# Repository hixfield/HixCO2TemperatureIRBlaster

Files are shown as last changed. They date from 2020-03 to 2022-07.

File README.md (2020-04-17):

![Build with PlatformIO](https://img.shields.io/badge/build%20with-PlatformIO-orange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)




Hardware (schematic and PCB) and software for a WIFI connected device offering lots of functionality: CO2 measuring, IR Transmitter, IR receiver and temperature sensor.
As output it has an OLED display, and RGB LED and beeper. Its based on the ESP8266 microcontroller and tts part of my home automation system based on a raspberry pi running Mosquitoo, Nodered, InfluxDB and Grafana.

## Improvements
- [ ] Add temperature offset in firware (seams device is reading hotter then ambient?)
- [ ] Switch to a passive buzzer (should get rid of the reset beeping)
- [ ] Add PCB jumper (solder) to endable/disable buzzer
- [ ] Configuration of WIFI SSID/PWD via web interface
- [ ] Extend firmware to support learning IR codes
- [ ] Extend firmware for remote sending on AC commands

## Brief overview

- Schematic and PCB design in Eagle
- WIFI connected
- MQTT firmware written using PlatformIO
- Plugs in the mains (no need for any USB seperate power brick)
- IR output: PCB has 3 possible positions for the IR Led just use the one convenient for you
- IR input (can be usefull to learn IR codes)
- measures the room temperature via DS18B20
- RGB Led to show green-orange-red depending on CO2 concentration
- Beeper on board
- 32x128 OLED dispaly
- based on popular [ESP8266](http://esp8266.com)

## Youtube movies

| 3D case design in Fusion 360. | Putting case and PCB together |
|---|---|
|3D case design in Fusion 360 (https://www.youtube.com/watch?v=IMcJwMR-dLY)|Putting case and PCB together (https://www.youtube.com/watch?v= ViuAWiBjCa4)

# overview
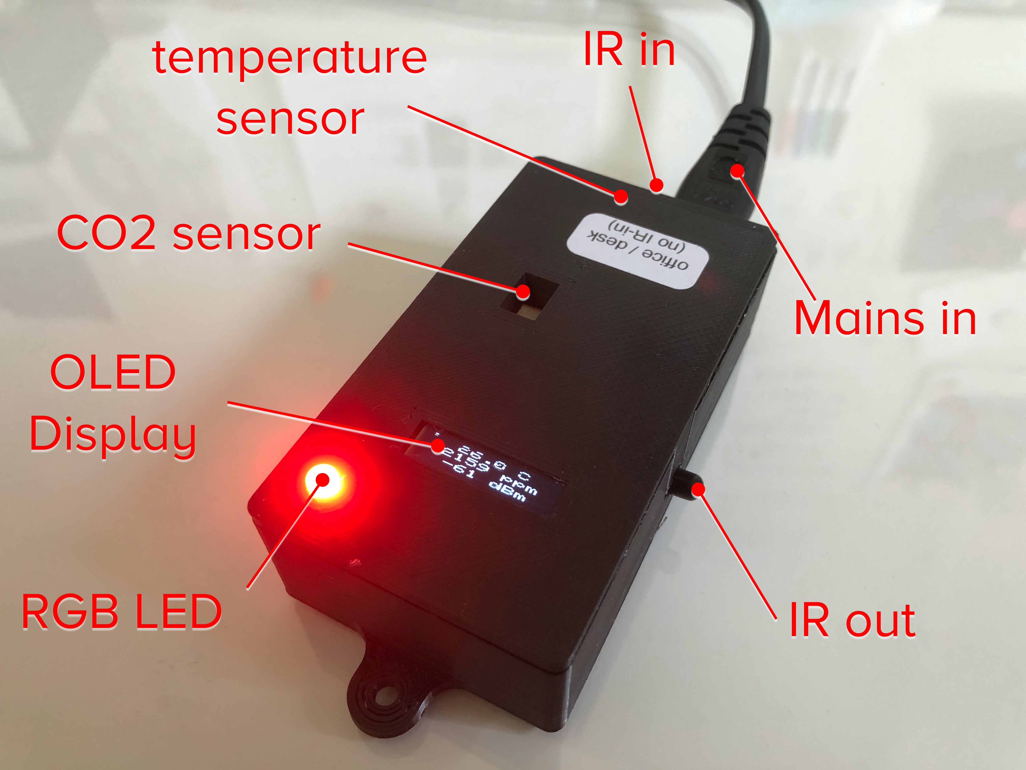
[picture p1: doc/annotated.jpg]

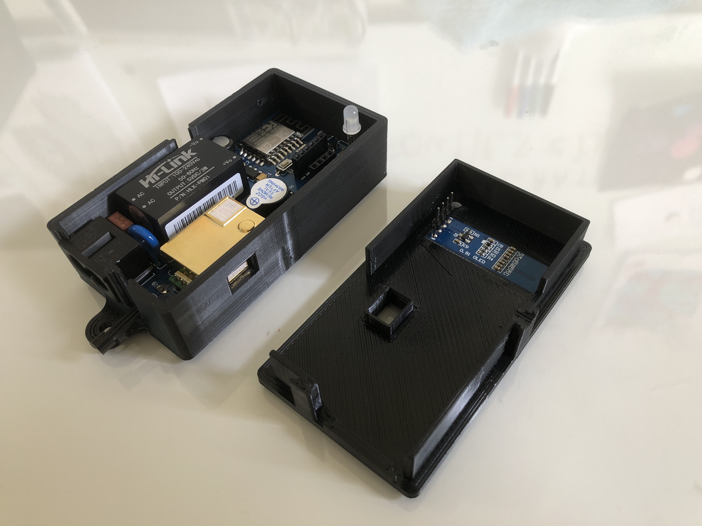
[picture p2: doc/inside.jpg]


# Hardware

[Click here for hardware information](hardware/README.md)

# Software

[Click here for software information](software/README.md)

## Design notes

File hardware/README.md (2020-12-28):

# HixCO2TemperatureIRBlaster - Hardware
The respository contains the EagleCAD file + JLCPCB zip export (in the `/hardware` folder)

| Top | Bottom |
|---|---|
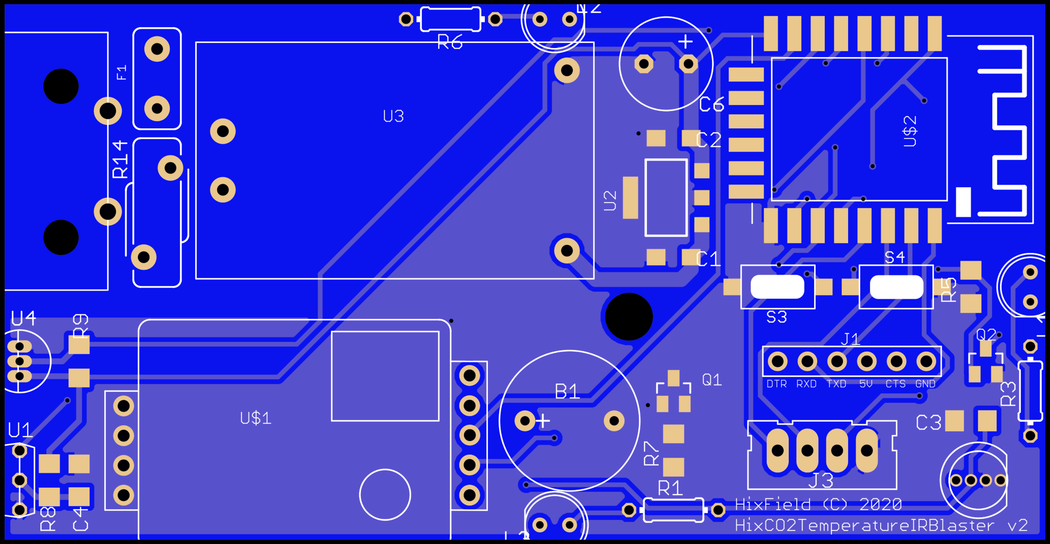
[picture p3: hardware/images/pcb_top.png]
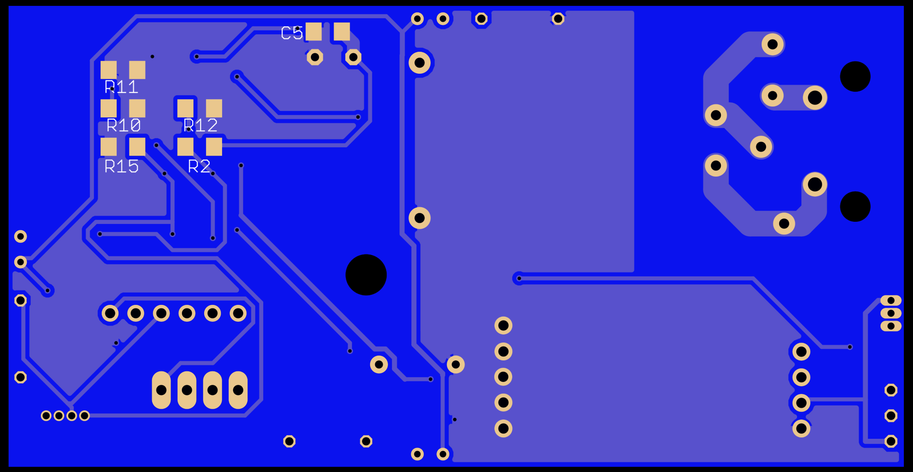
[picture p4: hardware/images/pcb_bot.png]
|  |  |

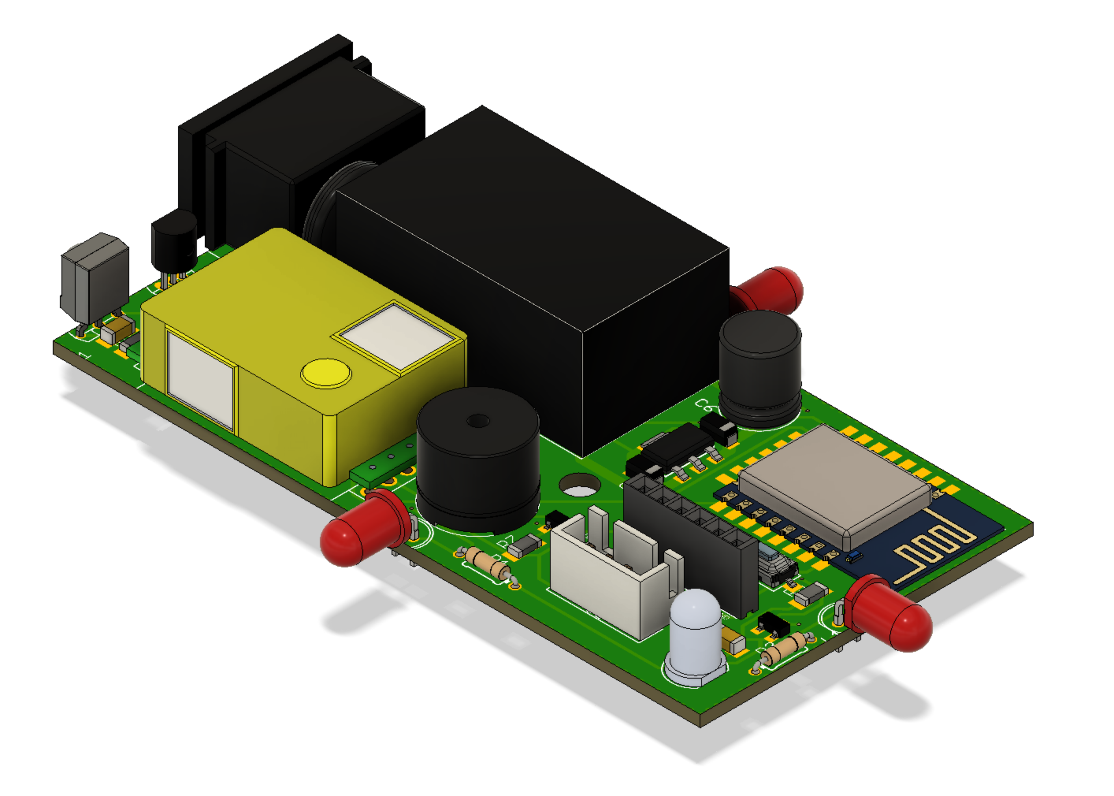
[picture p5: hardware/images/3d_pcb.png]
3D PCB


# BOM
## Base
| ID | Part |
|---|---
|B1 | BUZZER(12MM) 
|C1, C2 | 47uF (SMD 1206) 
|C3, C5 | 100nF (SMD 1206) 
|C6 | 680uF/6.3V 
|F1 | Fuse 800mA 250V 
|J1 | Header female 6 pin
|J2 | IEC320C8 mains connector 
|J3 | Header female 4 pin or XH4P 
|Q1 | Mosfet AO3400 
|R2, R7, R10, R11, R15 | 10K (SMD 1206) 
|R9 | 4.7K (SMD 1206)
|R12 | 2.2K (SMD 1206)  
|R14 | S10K275 
|S3, S4 | SMD Push button 
|U$2 | ESP8266(ESP12E)V2
|U$3 | RGB LED 5mm 
|U1 | TSOP2238 
|U2 | LM3940 (SMD) 
|U3 | HLK-PM01 (mains to 5v powerbrick) 
|U4 | DS18B20 *Eventhough I have designed the PCB to allow mounting a plain TO-92 DS18B20 externally, it seams to be highly inaccurate because (I suspect) it takes over the heat via its leads from the internal of the case/pcb. Therefore it is better to use an external DS18B20 probe. I have included a case design for a plain TO-92 and external sensor probe (with strain relief).*

## IR blasting (optional)
| ID | Part |
|---|---
|L1, L2, L3 | IR LED 100 mA. -> only assemble the one that points in the direction right for you!
|Q2 | Mosfet AO3400 
|R1, R3, R6 | 68 Ohm (SMD 1206) -> only assemble for the LED that points in the direction right for you! 
|R5 | 10K (SMD 1206) 

## IR receiving (optional)
| ID | Part |
|---|---
|C4 | 4.7uF (SMD 1206) 
|R8 | 100 Ohm (SMD 1206) 
|U1 | TSOP2238 

# Schematic
The repository contains the EagleCAD (in the `/hardware` folder)

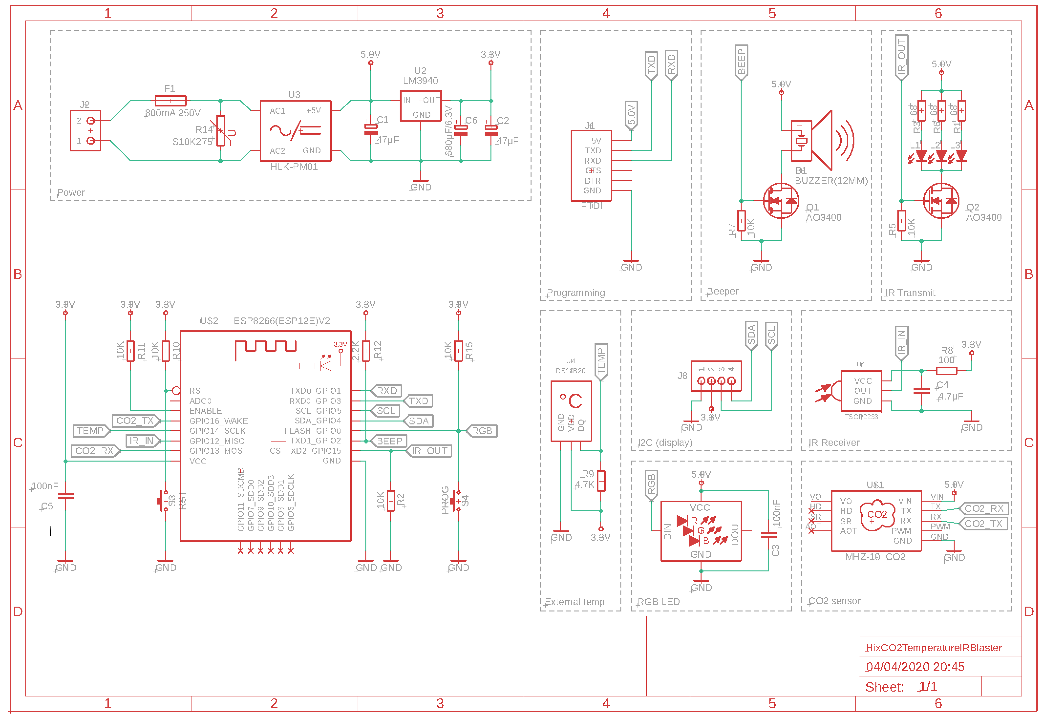
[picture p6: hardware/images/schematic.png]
Schematic


# 3D printed case
(the repository contains the stl files (`/hardware/case` folder)

## external DS18B20 sensor probe
| base | lid |
|---|---|
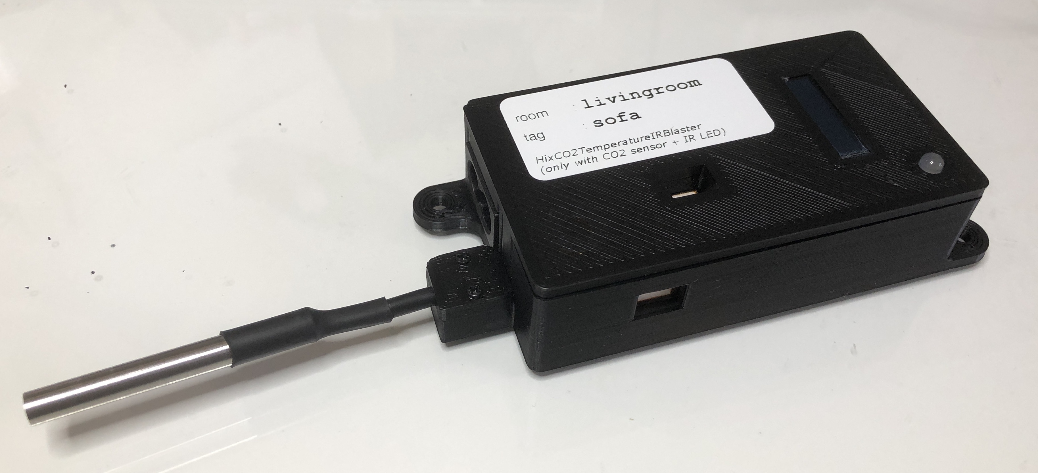
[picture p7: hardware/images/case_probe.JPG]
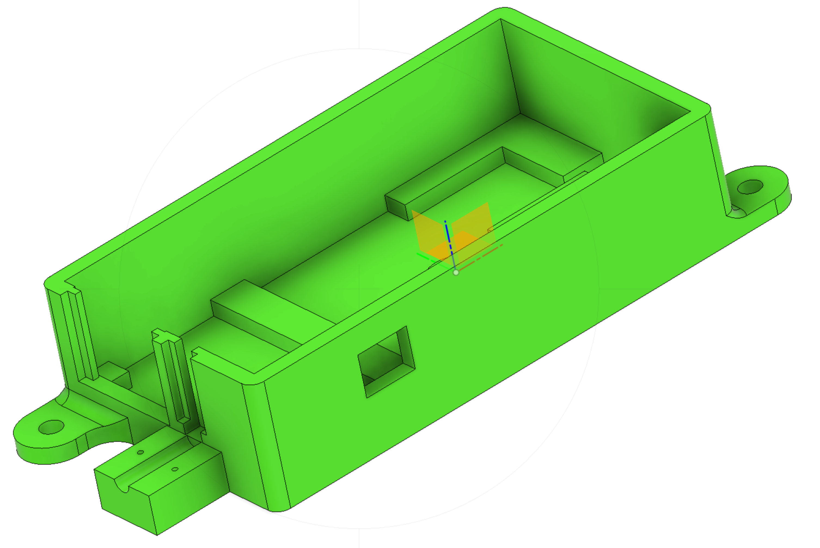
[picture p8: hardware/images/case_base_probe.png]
|  |  |
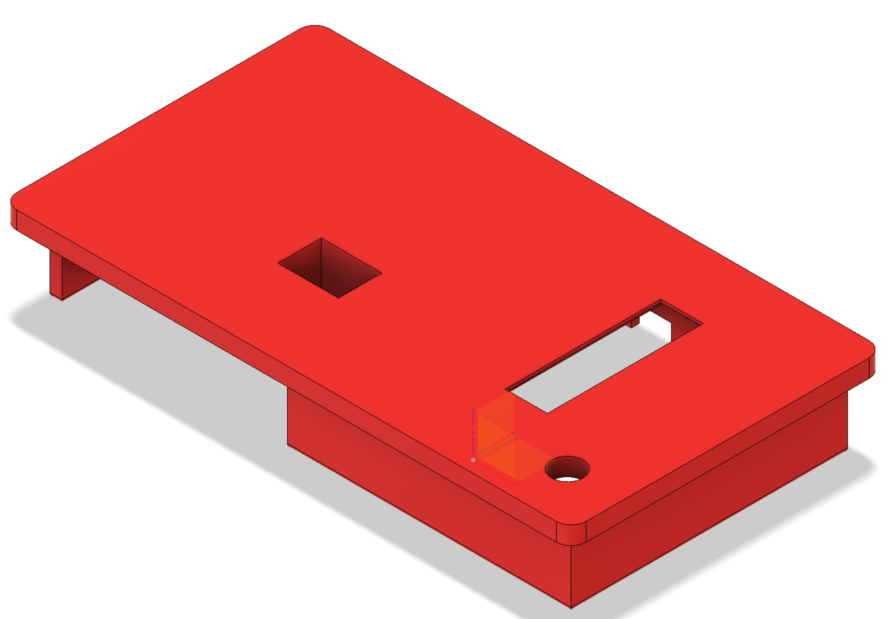
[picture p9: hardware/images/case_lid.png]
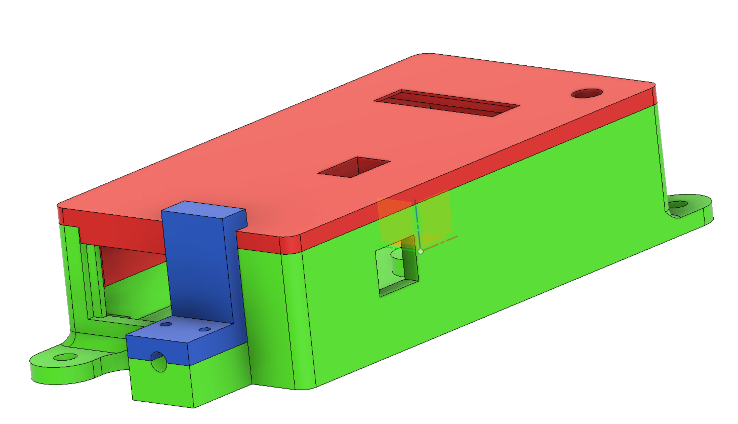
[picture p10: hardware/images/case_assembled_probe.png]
|  |  |

## plain TO-92 DS18B20 sensor

| base | lid |
|---|---|
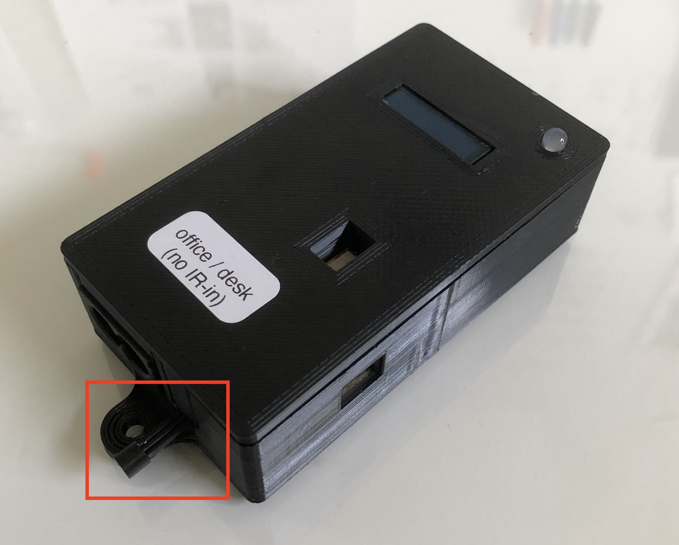
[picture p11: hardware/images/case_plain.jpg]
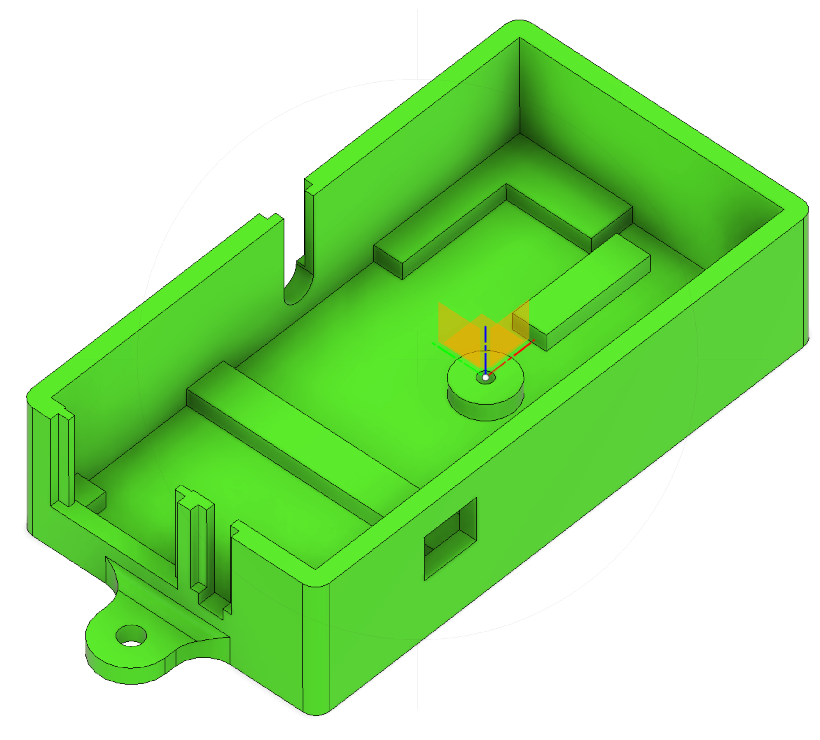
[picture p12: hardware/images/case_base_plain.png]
|  |  |
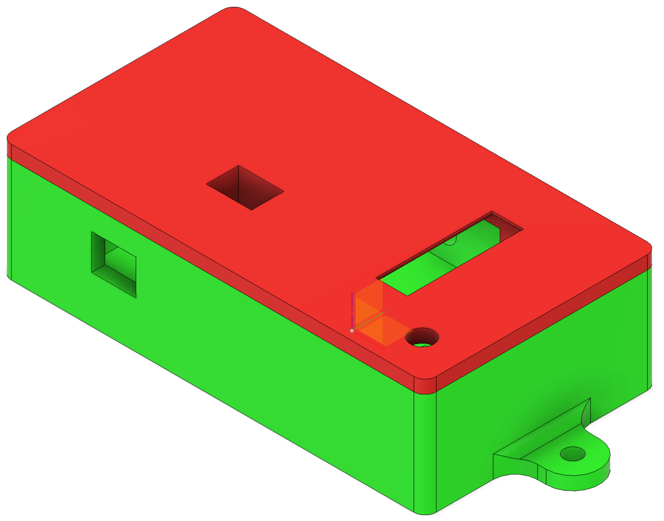
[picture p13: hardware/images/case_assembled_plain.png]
| PCB top view |  |

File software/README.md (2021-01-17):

# HixCO2TemperatureIRBlaster - Firmware

![Build with PlatformIO](https://img.shields.io/badge/build%20with-PlatformIO-orange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)



## How to flash the device

### Step 0: software confirmation
* make sure you have set your WIFI credentials in the secret.cpp
* make sure you have PlatformIO correctly setup in your Microsoft Visual Studio Code
* open the firmware in Microsoft Visual Studio Code

### Step 1: Initial upload via serial cable
* make sure your USB/FTDI is set to 5V
* insert your USB to FTDI onto J1 of the PCB
* press the switches in this order:
	- press RESET and hold
	- press PROG and hold
	- release PROG
	- release RESET
* this puts the device is programming mode (std ESP8266 procedure)
* if you have the buzzer installed, is should now be constantly beeping
* open the platformio.ini and configure the upload port and speed to use your USB/FTDI for example:
	- `upload_speed = 460800`
	- `upload_port = /dev/cu.usbserial-A50285BI`
* upload to the device
* during uploading the buzzer will make some different noises this is because its actually connect to an communication pin (normal)
* press the reset button and the device should boot, but it will take much longer then usual because the SPIFFS is not yet flashed

### Step 2: Upload the SPIFFS filesystem 
* seams to only work using `pio run -t uploadfs` (platformio "upload filesystem image" does not work)
* open terminal and execute the above command

### Step 3: switch to OTA
* reconfigure the platformio.ini file to now flash OTA:
	- `upload_protocol = espota`
	- `upload_port = 192.168.99.234` => **fill in the IP of YOUR device**
* try uploading the firmware again but this time OTA
* OTA uploading resets the device automatically so you don't have to press the RESET button (be patient!)
* now you can "Upload File Systems image" via Visual Studio Code / platformio

## MQTT

### Publishing

```
{room}
   └─── HixCO2TemperatureIRBlaster
           └─── {deviceTag}
                     └─── device
                     │       └─── count
                     │       └─── room
                     │       └─── device_type
                     │       └─── device_version
                     │       └─── device_tag
                     │       └─── device_name
                     │       └─── wifi_ssid
                     │       └─── wifi_ip
                     │       
                     └─── status
                     │       └─── count
                     │       └─── wifi_rssi
                     │       └─── co2
                     │       └─── temperature
                     │
                     └─── influxdb
```
#### `influxdb` topic publishing contents
To make the import in the influxdb from Node-RED as easy as possible the `influxdb` topic publishes a json document that can immediatly imported using the `influxdb in` node.
They only thing required is to convert it to a json object via the `To json` node.
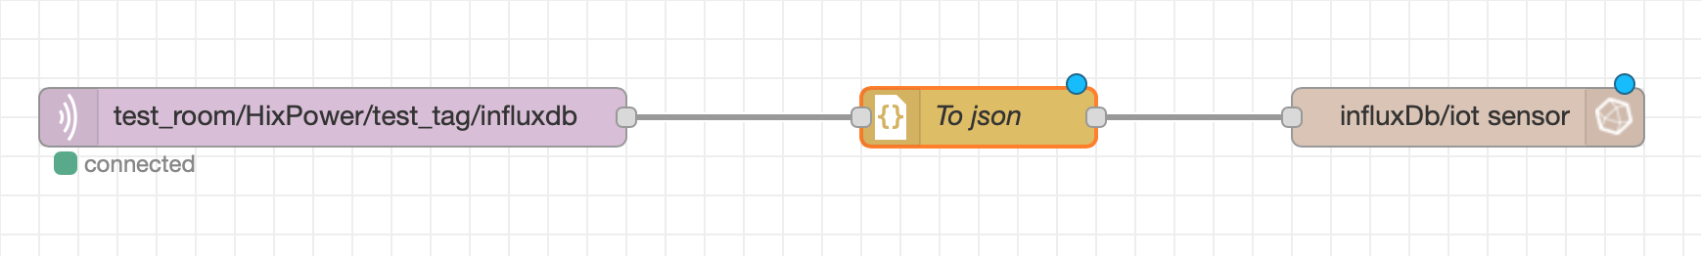
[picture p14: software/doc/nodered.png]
Node-RED influxDB import


Following the `influxdb in` node the json is an array where:

- the first element contains the measurements
- the second element contains the tags

```
  [
   {
      "co2"           : 4564,
      "temperature"   : 45,
      "wifi_rssi"     : -45
   },
   {
      "device_type"   : "HixCO2",
      "device_version": "2.5.8",
      "device_tag"    : "at_door"
      "room"          : "office",
      "wifi_ssid"     : "public_wifi"
   }
  ]
```

### Subscribing

This device does not subscribe to any topics

## Configuration web interface

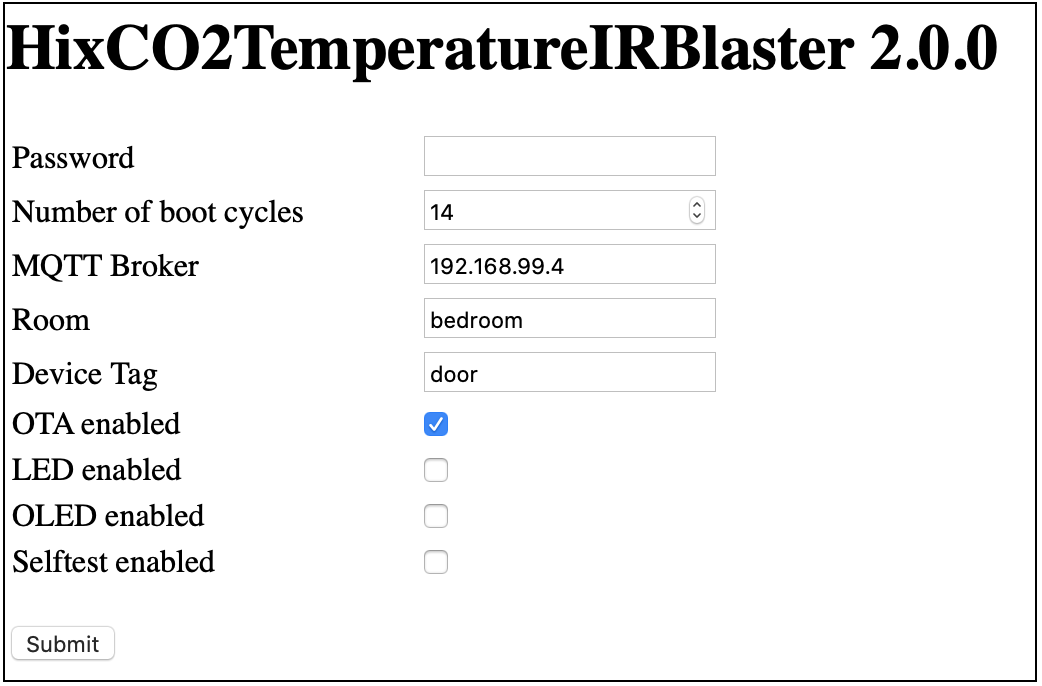
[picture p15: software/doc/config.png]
Config web interface


* Once connectted to the WIFI a normal browser can be used to configure:
 - the MQTT details.
 - OTA = Over The Air updating of the firmware
 - LED enabled (if the device is installed e.g in bedroom the LED can be annoying)
 - OLED display enabled (same comment as for LED)
 - Selftest enabled (if on beeps, blinks and transmits IR Samsun Airco off at boot)
* Just go the the device's ip address with your browser
* Password is intitially set as `bornem1973`.
* At this moment the WIFI SSID and password are hardcoded in the src/secret.cpp file

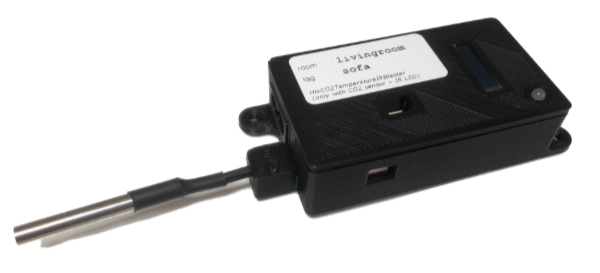
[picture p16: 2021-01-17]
hardware/images/case_probe.png

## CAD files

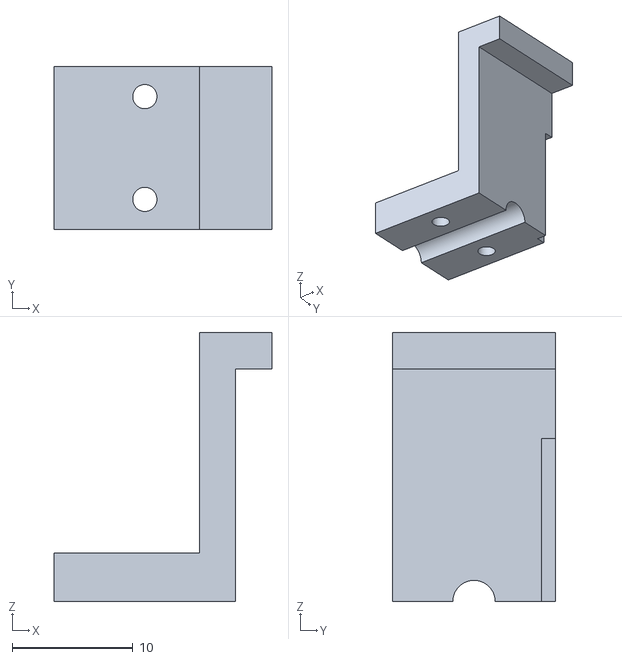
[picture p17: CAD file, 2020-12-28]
hardware/case/external ds18b20/case_sensortie.stl
18.0 x 13.5 x 22.3

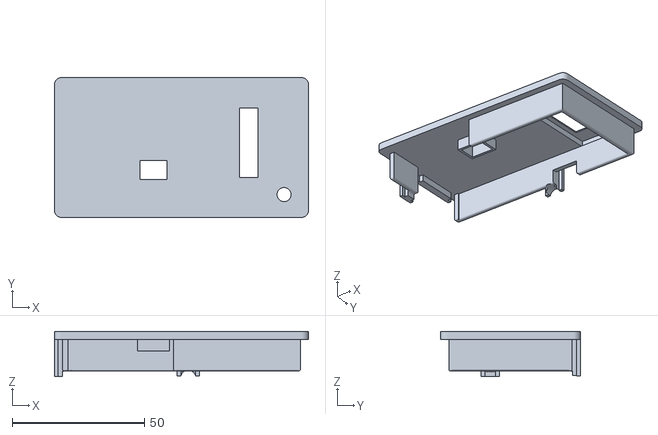
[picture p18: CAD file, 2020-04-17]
hardware/case/internal ds18b20/case_lid.stl
95.9 x 52.7 x 17.1

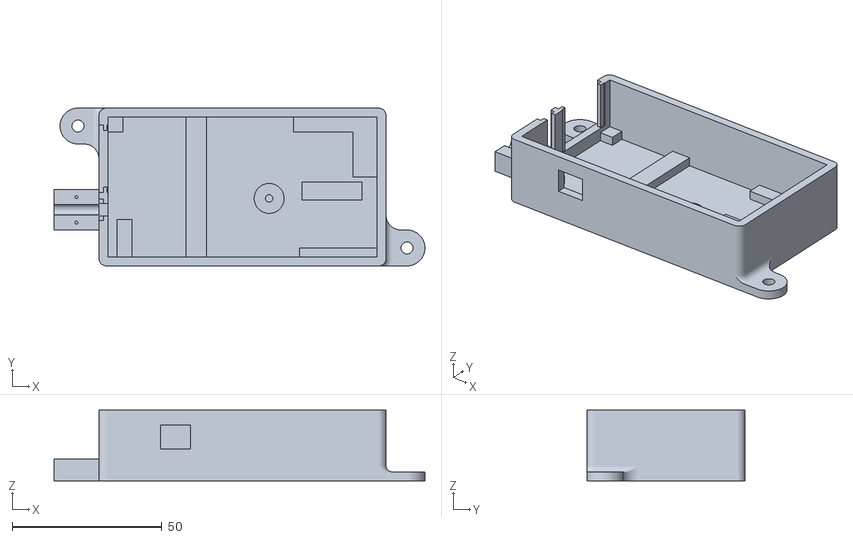
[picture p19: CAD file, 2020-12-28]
hardware/case/external ds18b20/case_base.stl
123.9 x 52.7 x 23.6

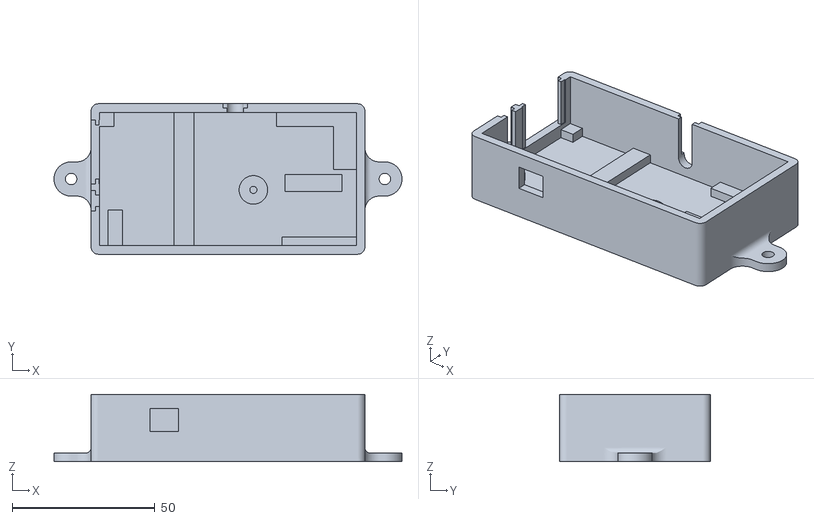
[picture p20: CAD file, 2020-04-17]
hardware/case/internal ds18b20/case_base.stl
121.9 x 52.7 x 23.6

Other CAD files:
hardware/case/external ds18b20/case_lid.stl

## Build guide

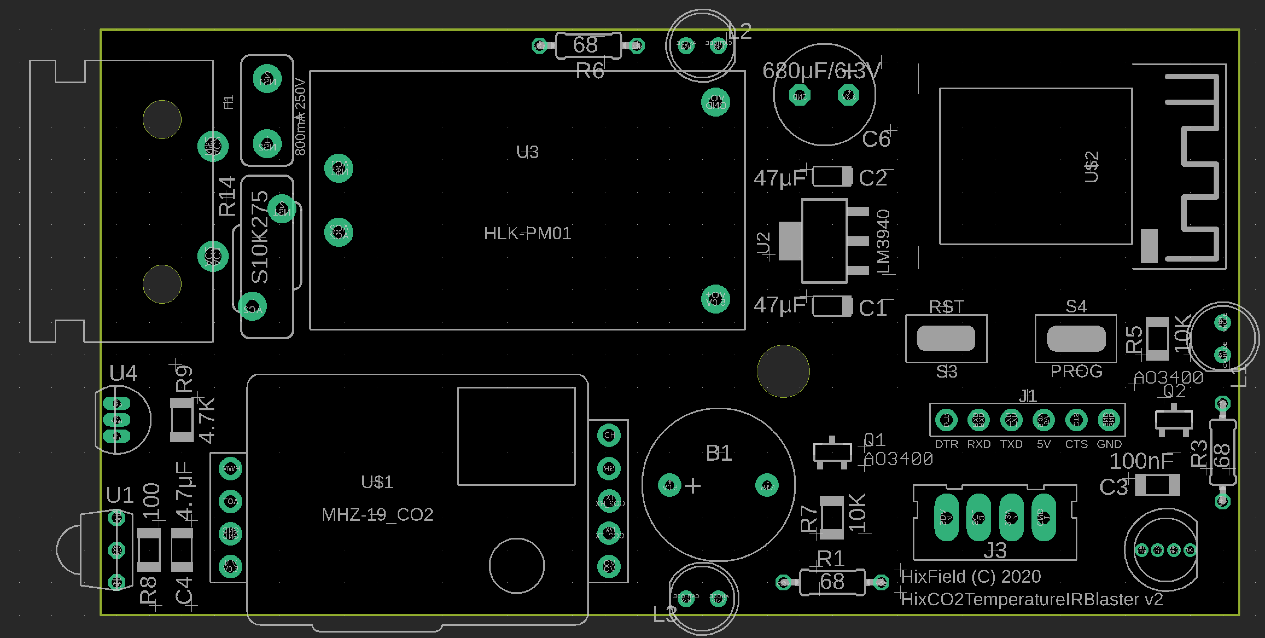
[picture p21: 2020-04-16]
hardware/images/solder_top.png

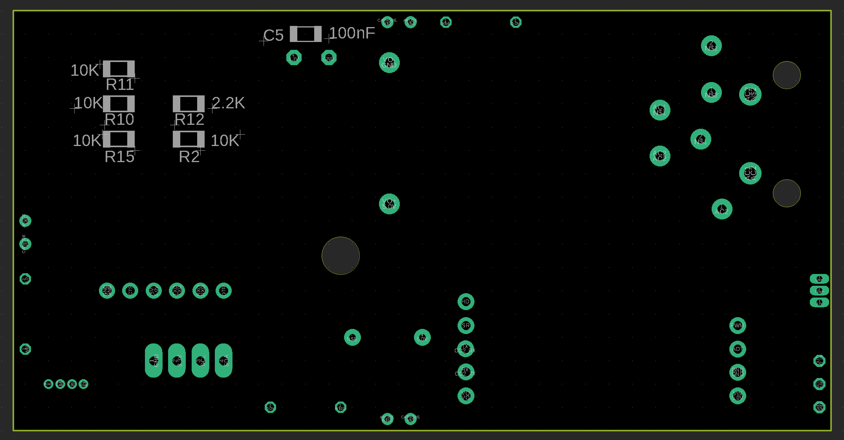
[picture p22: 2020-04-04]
hardware/images/solder_bottom.png

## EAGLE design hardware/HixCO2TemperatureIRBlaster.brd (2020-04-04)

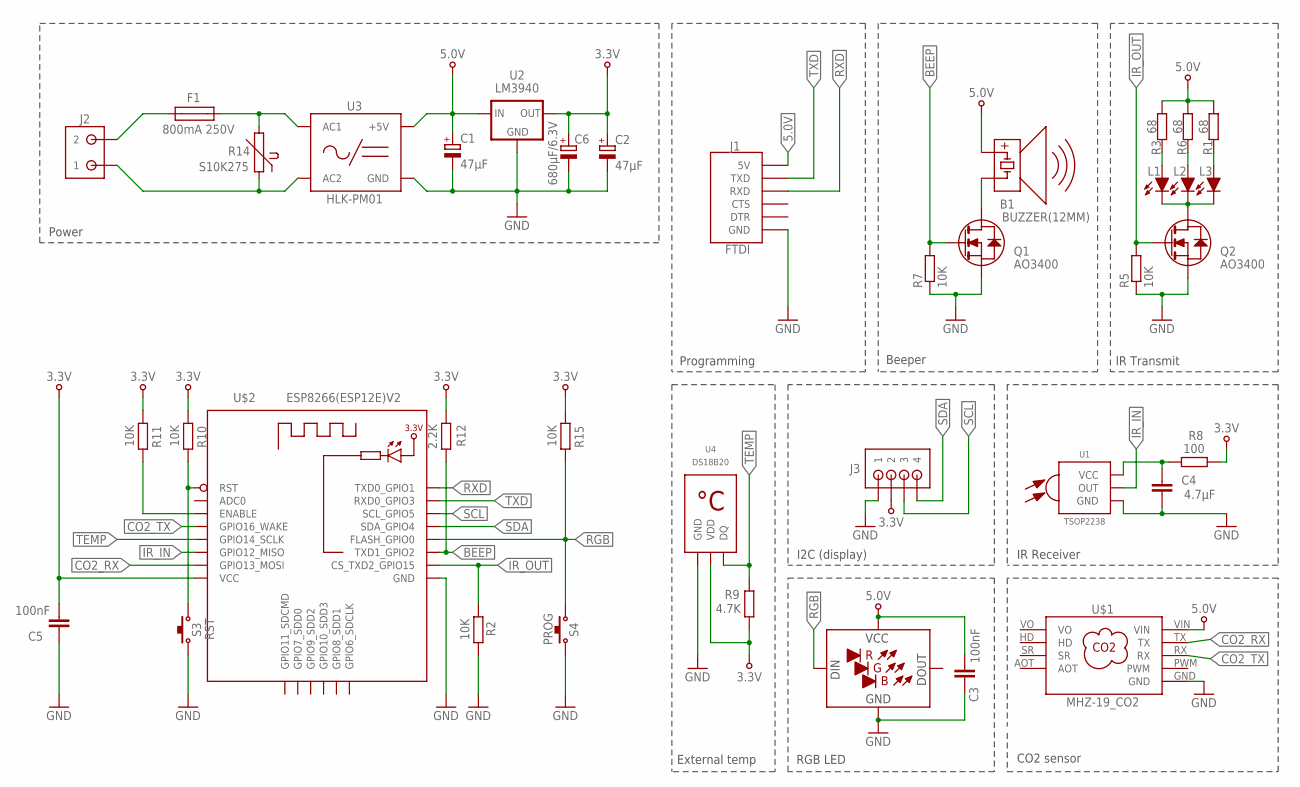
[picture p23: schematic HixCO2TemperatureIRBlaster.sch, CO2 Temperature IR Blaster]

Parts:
B1: BUZZER(12MM)
C1, C2: 47μF; SMC_A
C3, C5: 100nF; C1206
C4: 4.7μF; C1206
C6: 680μF/6.3V; ELKO_RADIAL_STRAIGHT_4P_8D_9H
F1: 800mA 250V; FUSE_508
J1: FTDI
J2: IEC320C8
J3: XH4P
L1, L2, L3: LEDLED5MM_ANGLED1; LED5MM_ANGLED1
Q1, Q2: AO3400; SOT23
R1, R3, R6: 68; 0204/7
R2, R5, R7, R10, R11, R15: 10K; R1206
R8: 100; R1206
R9: 4.7K; R1206
R12: 2.2K; R1206
R14: S10K275
S3: RST; SMDPUSHBTN_TYPE1
S4: PROG; SMDPUSHBTN_TYPE1
U1: TSOP2238
U2: LM3940; SOT223
U3: HLK-PM01
U4: DS18B20; TO-92(123)
U$1: MHZ-19_CO2
U$2: ESP8266(ESP12E)V2; ESP8266(ESP12E)
U$3: LED_RGB; LED_PL9823-F5

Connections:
3.3V: C2.+, C5.1, C6.+, J3.2, R8.2, R9.2, R10.2, R11.2, R12.2, R15.2, U2.3 (OUT), U4.3 (VDD), U$2.VCC
5.0V: B1.+, C1.+, C3.1, J1.5V, R1.2, R3.2, R6.2, U2.1 (IN), U3.VO+ (+5V), U$1.VIN, U$3.VCC
AC2: J2.AC1 (1), R14.1, U3.AC2
BEEP: Q1.1 (G), R7.2, R12.1, U$2.GPIO2_TXD1 (TXD1_GPIO2)
CO2_RX: U$1.TX, U$2.GPIO13_MOSI
CO2_TX: U$1.RX, U$2.GPIO16_WAKE
GND: C1.-, C2.-, C3.2, C4.2, C5.2, C6.-, J1.GND, J3.1, Q1.2 (S), Q2.2 (S), R2.1, R5.1, R7.1, S3.2, S4.2, U1.GND, U2.2 (GND), U2.4 (GND), U3.VO- (GND), U4.1 (GND), U$1.GND, U$2.GND, U$3.GND
IR_IN: U1.OUT, U$2.GPIO12_MISO
IR_OUT: Q2.1 (G), R2.2, R5.2, U$2.GPIO15_CS_TXD2 (CS_TXD2_GPIO15)
unnamed: F1.2, R14.2, U3.AC1
unnamed: F1.1, J2.AC2 (2)
unnamed: L1.CATHODE (C), L2.CATHODE (C), L3.CATHODE (C), Q2.3 (D)
unnamed: L2.ANODE (A), R6.1
unnamed: B1.-, Q1.3 (D)
unnamed: C4.1, R8.1, U1.VCC
unnamed: R10.1, S3.1, U$2.RST
unnamed: R11.1, U$2.ENABLE
unnamed: L1.ANODE (A), R3.1
unnamed: L3.ANODE (A), R1.1
RGB: R15.1, S4.1, U$2.GPIO0_FLASH (FLASH_GPIO0), U$3.DIN
RXD: J1.RXD, U$2.GPIO1_TXD0 (TXD0_GPIO1)
SCL: J3.3, U$2.GPIO5_SCL (SCL_GPIO5)
SDA: J3.4, U$2.GPIO4_SDA (SDA_GPIO4)
TEMP: R9.1, U4.2 (DQ), U$2.GPIO14_SCLK
TXD: J1.TXD, U$2.GPIO3_RXD0 (RXD0_GPIO3)
VO: U$1.VO

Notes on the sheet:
Power
Programming
Beeper
External temp
IR Transmit
I2C (display)
IR Receiver
CO2 sensor
RGB LED

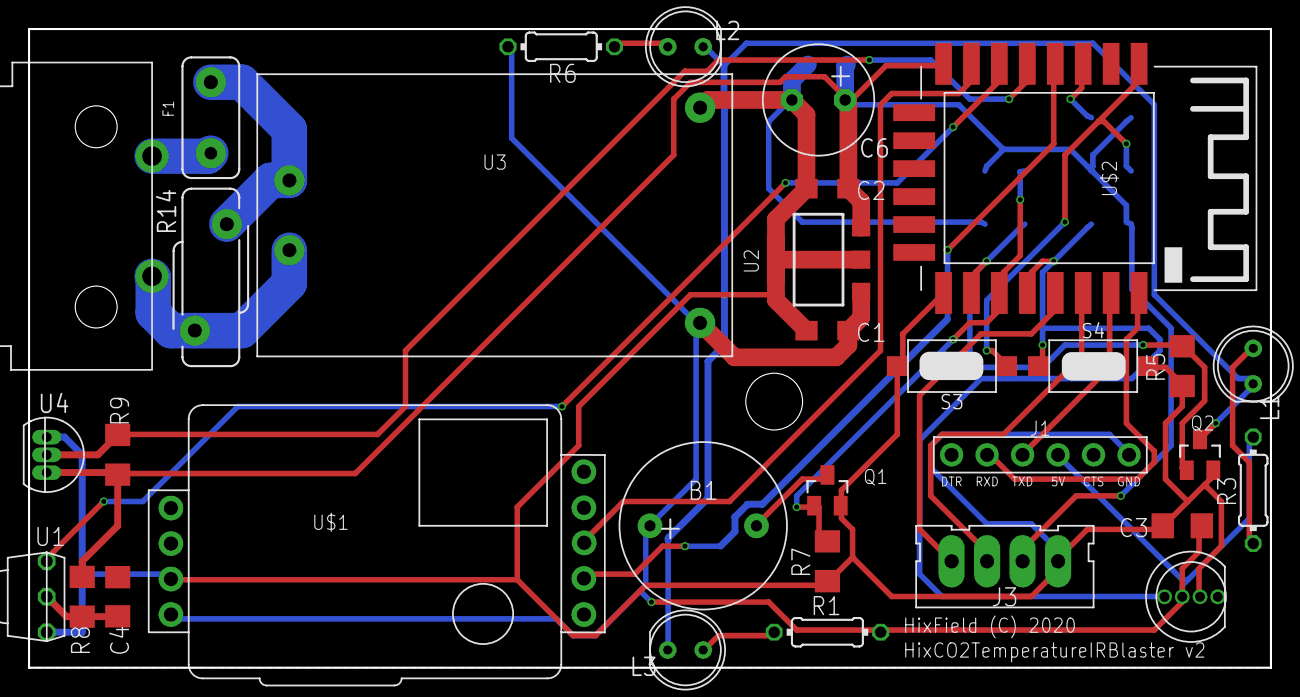
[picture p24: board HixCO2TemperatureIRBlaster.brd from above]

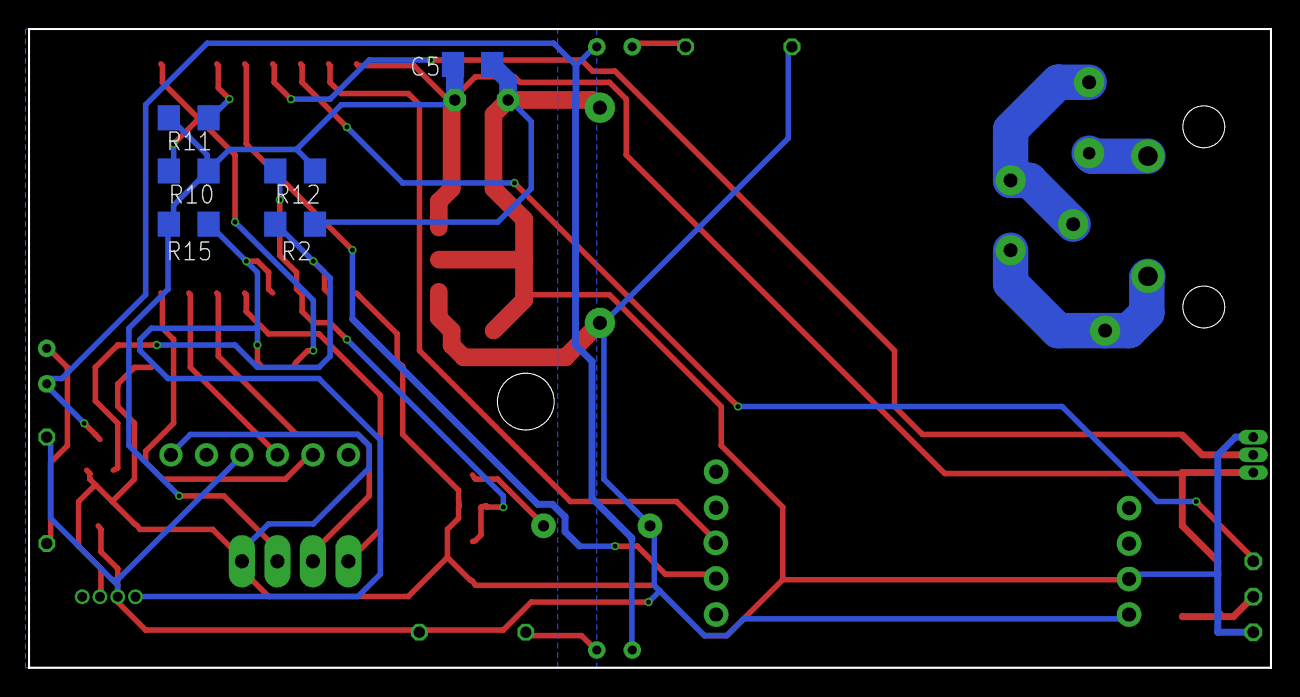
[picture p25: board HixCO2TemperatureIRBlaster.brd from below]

Board: 2 copper layers, 88.9 x 45.7 mm, 38 parts (6 on the bottom side), 25 nets.

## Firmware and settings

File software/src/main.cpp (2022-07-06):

#include "HixConfig.h"
#include "HixDisplay.h"
#include "HixMQTT.h"
#include "HixWebServer.h"
#include "secret.h"
#include <Adafruit_NeoPixel.h>
#include <Arduino.h>
#include <ArduinoOTA.h>
#include <HixDS18B20.h>
#include <HixPinDigitalOutput.h>
#include <HixTimeout.h>
#include <MHZ19.h>
#include <SoftwareSerial.h>

// connected devices and software modules
HixConfig           g_config;
HixTimeout          g_sampler(1000, true);
HixTimeout          g_logger(5000, true);
HixTimeout          g_noConnectionReset(5UL * 60UL * 1000UL);
HixDisplay          g_display;
HixPinDigitalOutput g_beeper(2);
HixDS18B20          g_temperature(14);
Adafruit_NeoPixel   g_rgbLed = Adafruit_NeoPixel(1, 0, NEO_RGB + NEO_KHZ400);
MHZ19               g_mhz19;
SoftwareSerial      g_mhz19Serial(13, 16);
HixWebServer        g_webServer(g_config, g_mhz19);

// Not used in this firmware:
// IRSamsungAc         g_IRTransmitter(15);
// IRrecv g_IRReciever(12, 1024, 40, true);

// global variables
float g_fCurrentTemp = 0;
int   g_nCurrentCO2  = 0;
int   g_nCurrentRSSI = 0;
bool  g_bLoopToggle  = false;

HixMQTT g_mqtt(Secret::WIFI_SSID,
               Secret::WIFI_PWD,
               g_config.getMQTTServer(),
               g_config.getDeviceType(),
               g_config.getDeviceVersion(),
               g_config.getRoom(),
               g_config.getDeviceTag(),
               g_config.getDeviceBuildTimestamp());

enum Color : uint32_t {
    black  = 0x000000,
    white  = 0xFFFFFF,
    red    = 0xFF0000,
    green  = 0x00FF00,
    blue   = 0x0000FF,
    orange = 0xFF8C00
};

//////////////////////////////////////////////////////////////////////////////////
// Helper functions
//////////////////////////////////////////////////////////////////////////////////

void resetWithMessage(const char * szMessage) {
    Serial.println(szMessage);
    delay(2000);
    ESP.reset();
}

void configureOTA() {
    Serial.println("Configuring OTA, my hostname:");
    Serial.println(g_mqtt.getMqttClientName());
    ArduinoOTA.setHostname(g_mqtt.getMqttClientName());
    ArduinoOTA.setPort(8266);
    // setup handlers
    ArduinoOTA.onStart([]() {
        Serial.println("OTA -> Start");
    });
    ArduinoOTA.onEnd([]() {
        Serial.println("OTA -> End");
    });
    ArduinoOTA.onProgress([](unsigned int progress, unsigned int total) {
        Serial.printf("OTA -> Progress: %u%%\r", (progress / (total / 100)));
    });
    ArduinoOTA.onError([](ota_error_t error) {
        Serial.printf("OTA -> Error[%u]: ", error);
        if (error == OTA_AUTH_ERROR)
            Serial.println("OTA -> Auth Failed");
        else if (error == OTA_BEGIN_ERROR)
            Serial.println("OTA -> Begin Failed");
        else if (error == OTA_CONNECT_ERROR)
            Serial.println("OTA -> Connect Failed");
        else if (error == OTA_RECEIVE_ERROR)
            Serial.println("OTA -> Receive Failed");
        else if (error == OTA_END_ERROR)
            Serial.println("OTA -> End Failed");
    });
    ArduinoOTA.begin();
}

void setLedColor(Color color, u32_t nDimFactor = 16) {
    // make base colors
    u32_t nR = color >> 16;
    u32_t nG = (color & 0x00FF00) >> 8;
    u32_t nB = color & 0x0000FF;
    // take dimming into account
    nR /= nDimFactor;
    nG /= nDimFactor;
    nB /= nDimFactor;
    // reassemble
    u32_t nDimmedColor = (nR << 16) | (nG << 8) | nB;
    g_rgbLed.setPixelColor(0, nDimmedColor);
    g_rgbLed.show();
}

void setLedColorForCO2(int nCO2ppm) {
    if (nCO2ppm < 800) {
        setLedColor(Color::green);
        return;
    }
    if (nCO2ppm < 1200) {
        setLedColor(Color::orange);
        return;
    }
    setLedColor(Color::red);
}

void printInfoMhz() {
    char myVersion[4];
    g_mhz19.getVersion(myVersion);
    Serial.print("\nFirmware Version: ");
    for (byte i = 0; i < 4; i++) {
        Serial.print(myVersion[i]);
        if (i == 1)
            Serial.print(".");
    }
    Serial.println("");
    Serial.print("Range: ");
    Serial.println(g_mhz19.getRange());
    Serial.print("Background CO2: ");
    Serial.println(g_mhz19.getBackgroundCO2());
    Serial.print("Temperature Cal: ");
    Serial.println(g_mhz19.getTempAdjustment());
    Serial.print("ABC Status: ");
    g_mhz19.getABC() ? Serial.println("ON") : Serial.println("OFF");
}

void selfTest(void) {
    Serial.println(F("Running self test..."));
    // display version while running the self test...
    Serial.println(F("Showing version on display"));
    g_display.drawDisplayVersion(g_config.getDeviceType(), g_config.getDeviceVersion());
    // show colors on led
    Serial.println(F("Showing green-red-oragne-blue-white on LED"));
    setLedColor(Color::green);
    delay(300);
    setLedColor(Color::red);
    delay(300);
    setLedColor(Color::orange);
    delay(300);
    setLedColor(Color::blue);
    delay(300);
    setLedColor(Color::white);
    // beep our led 5 times
    Serial.println(F("Beeping 5 times"));
    g_beeper.blink(true, 5, 100);
    // extract info of the CO2 sensor
    printInfoMhz();
    // all done
    Serial.println(F("Selftest complete"));
}

//////////////////////////////////////////////////////////////////////////////////
// Setup
//////////////////////////////////////////////////////////////////////////////////

void setup() {
    Serial.begin(115200);
    // start with a clean line
    Serial.println();
    Serial.println();
    // display my version
    Serial.print(F("Startup "));
    Serial.print(g_config.getDeviceType());
    Serial.print(F(" "));
    Serial.println(g_config.getDeviceVersion());
    // increment our counter
    g_config.incrementNumberOfBootUps();
    Serial.print(F("Number of bootups: "));
    Serial.println(g_config.getNumberOfBootUps());
    // disconnect WiFi -> seams to help for bug that after upload wifi does not want to connect again...
    Serial.println(F("Disconnecting WIFI"));
    WiFi.disconnect();
    // setup display
    Serial.println(F("Setting up display"));
    if (!g_display.begin()) resetWithMessage("SSD1306 allocation failed, resetting");
    g_display.clearDisplay();
    g_display.display();
    // setup beeper
    Serial.println(F("Setup beeper"));
    g_beeper.begin();
    // setup DS18B20
    Serial.println(F("Setup DS18B20"));
    if (!g_temperature.begin()) {
        resetWithMessage("Could not locate DS18B20");
    }
    // setup RGB let
    Serial.println(F("Setup RDB LED"));
    g_rgbLed.begin();
    setLedColor(Color::black);
    // setup CO2 sensor
    Serial.println(F("Setting up CO2 sensor"));
    g_mhz19Serial.begin(9600);
    g_mhz19.begin(g_mhz19Serial);
    g_mhz19.setRange(2000);
    g_mhz19.autoCalibration(g_config.getAutoBackgroundCalibrationEnabled());
    // configure MQTT
    Serial.println(F("Setting up MQTT"));
    if (!g_mqtt.begin()) resetWithMessage("MQTT allocation failed, resetting");
    // setup SPIFFS
    Serial.println(F("Setting up SPIFFS"));
    if (!SPIFFS.begin()) resetWithMessage("SPIFFS initialization failed, resetting");
    // setup the server
    Serial.println(F("Setting up web server"));
    g_webServer.begin();
    // run selftest if required
    if (g_config.getSelfTestEnabled()) {
        selfTest();
    }
    // all done
    Serial.println(F("Setup complete"));
}

//////////////////////////////////////////////////////////////////////////////////
// Loop
//////////////////////////////////////////////////////////////////////////////////

void loop() {
    // other loop functions
    g_mqtt.loop();
    g_webServer.handleClient();
    ArduinoOTA.handle();
    // my own processing
    if (g_sampler.isExpired(true)) {
        g_bLoopToggle = !g_bLoopToggle;
        // load CO2 and check error condition
        int nTempCO2 = g_config.rescaleCO2Value(g_mhz19.getCO2());
        // only use the new value if there was no error
        if (g_mhz19.errorCode == RESULT_OK) {
            g_nCurrentCO2 = nTempCO2;
        }
        // read other sensor values
        g_fCurrentTemp = g_temperature.getTemp();
        g_nCurrentRSSI = WiFi.RSSI();
        // set led
        if (g_config.getLEDEnabeled()) {
            if (!g_mqtt.isWifiConnected()) {
                setLedColor(Color::blue);
            } else {
                if (g_mqtt.isConnected()) {
                    setLedColorForCO2(g_nCurrentCO2);
                } else {
                    setLedColor(Color::white);
                }
            }
        } else {
            setLedColor(Color::black);
        }
        // show on display
        if (g_config.getOLEDEnabled()) {
            g_display.showStatus(g_fCurrentTemp,
                                 g_nCurrentCO2,
                                 g_nCurrentRSSI,
                                 g_bLoopToggle);
        }
        // log to serial
        Serial.print(g_fCurrentTemp);
        Serial.print(F(" °C ; "));
        Serial.print(g_nCurrentCO2);
        Serial.print(F(" ppm ; "));
        Serial.print(g_nCurrentRSSI);
        Serial.print(F(" dbm"));
        Serial.println();
    }
    if (g_logger.isExpired(true)) {
        g_mqtt.publishStatusValues(g_nCurrentCO2, g_fCurrentTemp);
    }
    if (g_mqtt.isConnected()) {
        g_noConnectionReset.restart();
    }
    if (g_noConnectionReset.isExpired(true)) {
        resetWithMessage("MQTT connection timeout: resetting!");
    }
}

//////////////////////////////////////////////////////////////////////////////////
// Required by the MQTT library
//////////////////////////////////////////////////////////////////////////////////

void onConnectionEstablished() {
    // setup OTA
    if (g_config.getOTAEnabled()) {
        configureOTA();
    } else {
        Serial.println("OTA is disabled");
    }
    // plushing values
    g_mqtt.publishDeviceValues();
}

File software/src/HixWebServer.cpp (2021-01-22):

#include "HixWebServer.h"
#include "secret.h"
#include <FS.h>

HixWebServer::HixWebServer(HixConfig & config, MHZ19 & mhz19) : ESP8266WebServer(80),
                                                                m_config(config),
                                                                m_mhz19(mhz19) {
    onNotFound([this]() {
        if (!handleFileRead(uri()))
            send(404, "text/plain", "404: Not Found");
    });
}

String HixWebServer::getContentType(String filename) {
    if (filename.endsWith(".htm"))
        return "text/html";
    else if (filename.endsWith(".html"))
        return "text/html";
    else if (filename.endsWith(".css"))
        return "text/css";
    else if (filename.endsWith(".js"))
        return "application/javascript";
    else if (filename.endsWith(".png"))
        return "image/png";
    else if (filename.endsWith(".gif"))
        return "image/gif";
    else if (filename.endsWith(".jpg"))
        return "image/jpeg";
    else if (filename.endsWith(".ico"))
        return "image/x-icon";
    else if (filename.endsWith(".xml"))
        return "text/xml";
    else if (filename.endsWith(".pdf"))
        return "application/x-pdf";
    else if (filename.endsWith(".zip"))
        return "application/x-zip";
    else if (filename.endsWith(".gz"))
        return "application/x-gzip";
    return "text/plain";
}

bool HixWebServer::shouldReplacePlaceholders(String filename) {
    if (filename.endsWith(".htm")) return true;
    if (filename.endsWith(".html")) return true;
    return false;
}

// send the right file to the client (if it exists)
bool HixWebServer::handleFileRead(String path) {
    Serial.println("handleFileRead: " + path);
    //check for postback of config data
    if (path.endsWith("/postconfig")) {
        handlePostConfig();
        return true;
    }
    //check calibration of data...
    if (path.endsWith("/calibrate")) {
        handleCalibrate();
        return true;
    }
    // If a folder is requested, send the index file
    if (path.endsWith("/")) path += "index.html";
    // Get the MIME type
    String contentType = getContentType(path);
    if (SPIFFS.exists(path)) {
        File file = SPIFFS.open(path, "r");
        if (shouldReplacePlaceholders(path)) {
            String contents = file.readString();
            m_config.replacePlaceholders(contents);
            replacePlaceholdersMHZ19(contents);
            //send it
            send(200, contentType, contents);
        } else {
            streamFile(file, contentType);
        }
        //close our input file
        file.close();
        //return non error
        return true;
    }
    //file not found
    return false;
}


bool HixWebServer::handlePostConfig(void) {
    //check password
    if (arg("password") != Secret::CONFIG_PWD) {
        send(400, "text/plain", "Bad password");
        return false;
    }
    //handle parameters
    if (hasArg("nbr_bootups")) m_config.setNumberOfBootUps(arg("nbr_bootups").toInt());
    if (hasArg("mqtt_server")) m_config.setMQTTServer(arg("mqtt_server").c_str());
    if (hasArg("room")) m_config.setRoom(arg("room").c_str());
    if (hasArg("device_tag")) m_config.setDeviceTag(arg("device_tag").c_str());
    if (hasArg("scale_corr_factor")) m_config.setScaleCorrectFactor(arg("scale_corr_factor").toInt());
    m_config.setOTAEnabled(hasArg("ota_enabled"));
    m_config.setLEDEnabled(hasArg("led_enabled"));
    m_config.setOLEDEnabled(hasArg("oled_enabled"));
    m_config.setSelfTestEnabled(hasArg("selftest_enabled"));
    m_config.setAutoBackgroundCalibrationEnabled(hasArg("abc_enabled"));
    //write to epprom
    m_config.commitToEEPROM();
    //send reply
    const char * szSavedHtml = "/saved.html";
    File         file        = SPIFFS.open(szSavedHtml, "r");
    streamFile(file, getContentType(String(szSavedHtml)));
    file.close();
    //reset!
    delay(1000);
    ESP.reset();
    return true;
}

bool HixWebServer::handleCalibrate(void) {
    //check password
    if (arg("password") != Secret::CONFIG_PWD) {
        send(400, "text/plain", "Bad password");
        return false;
    }
    //calibrate
    m_mhz19.calibrate();
    //send reply
    const char * szSavedHtml = "/calibrate.html";
    File         file        = SPIFFS.open(szSavedHtml, "r");
    streamFile(file, getContentType(String(szSavedHtml)));
    file.close();
    //return non error
    return true;
}

void HixWebServer::replacePlaceholdersMHZ19(String & contents) {
    //extract version
    char versionArray[4];
    m_mhz19.getVersion(versionArray);
    String version;
    version += versionArray[0];
    version += versionArray[1];
    version += '.';
    version += versionArray[2];
    version += versionArray[3];
    //replace different parameters
    contents.replace("||MHZ19_FIRMWARE||", version);
    contents.replace("||MHZ19_CO2||", String(m_mhz19.getCO2()));
    contents.replace("||MHZ19_CO2_CORR||", String(m_config.rescaleCO2Value(m_mhz19.getCO2())));    
    contents.replace("||MHZ19_TRANSMITTANCE||", String(m_mhz19.getTransmittance()));
    contents.replace("||MHZ19_TEMPERATURE||", String(m_mhz19.getTemperature()));
    contents.replace("||MHZ19_ACCURACY||", String(m_mhz19.getAccuracy()));
    contents.replace("||MHZ19_RANGE||", String(m_mhz19.getRange()));
    contents.replace("||MHZ19_BACKGROUNDCO2||", String(m_mhz19.getBackgroundCO2()));
    contents.replace("||MHZ19_TEMPERATURECAL||", String(m_mhz19.getTempAdjustment()));
    contents.replace("||MHZ19_ABC||", m_mhz19.getABC() ? "ON" : "OFF");
}

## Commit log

2020-03-02 added hardware
    [HixCO2TemperatureIRBlaster.brd, HixCO2TemperatureIRBlaster.sch]
2020-03-03 update hardware
    [HixCO2TemperatureIRBlaster.brd, HixCO2TemperatureIRBlaster.sch]
2020-03-04 continued working on hardware models
    [HixCO2TemperatureIRBlaster.brd, HixCO2TemperatureIRBlaster.sch]
2020-03-06 updated esp pin mapping
    [HixCO2TemperatureIRBlaster.brd, HixCO2TemperatureIRBlaster.sch]
2020-03-08 electronic hardware v1 complete
    [HixCO2TemperatureIRBlaster.brd, HixCO2TemperatureIRBlaster.sch]
2020-03-30 added board testing software version
2020-04-02 continued working
    [HixCO2TemperatureIRBlaster.brd, HixCO2TemperatureIRBlaster.sch]
2020-04-04 Fixed short-circuit between 3.3V and 5.0V on board layout
    [HixCO2TemperatureIRBlaster.brd, HixCO2TemperatureIRBlaster.sch]
2020-04-10 fixed html page issue and led now complete black when disabled via html config
    [HixWebServer.cpp, main.cpp]
2020-04-17 updated documentation
    [case_base.stl, case_lid.stl]
2020-04-17 dimmed the RGB led
2020-04-17 added firmware define to disable the IR IN (seams to make firware unstable -> sudden resets?)
    [main.cpp]
2020-04-18 check if CO2 value is valid added reset info the config page
    [main.cpp]
2020-12-13 update readme split bom
2020-12-25 added device info to config page and calibration options
2020-12-28 added info and case for external DS18B20 probe
    [case_base.stl, case_lid.stl, case_sensortie.stl]
2021-01-22 added co2 scale correction factor
    [HixWebServer.cpp, main.cpp]
2021-08-27 added reset timeout for mqtt connection
    [main.cpp]
2022-07-06 led now white if no MQTT connection (blue means no wifi connection now)

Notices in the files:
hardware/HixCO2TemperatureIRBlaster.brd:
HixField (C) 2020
